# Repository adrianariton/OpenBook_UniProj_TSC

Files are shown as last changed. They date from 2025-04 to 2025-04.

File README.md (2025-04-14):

# Ariton Adrian TSC - proiect

# Implementation Steps

1. **Schematic Creation**
2. **Push to 2D PCB**
3. **Routing**
   - GND plane  
   - Net Class for Power Trails  
   - Custom rules & constraints upload  
   - Routing
4. **3D Models Design from Datasheets**
   - Battery  
   - Screen

---

# Hardware Modules and Components

## ESP32-C6-WROOM-1-N8 – Main Microcontroller
- WiFi 6, Bluetooth 5 LE, RISC-V core  
- Power Supply: 3.3V  
- Communications: SPI, I2C, UART, GPIO  

## SD Card Module
- Interface: SPI  
- Pins Used:
  - `SS_SD` → IO4  
  - `MOSI` → IO7  
  - `MISO` → IO2  
  - `SCK` → IO6  

## E-Paper Display
- Interface: SPI  
- Pins Used:
  - `EPD_CS` → IO10  
  - `EPD_DC` → IO5  
  - `EPD_RST` → IO23  
  - `EPD_BUSY` → IO3 (shared with MISO)  
  - MOSI, SCK (shared with SD)

## RTC Module - DS3231SN
- Interface: I2C  
- Pins Used:
  - `SCL` → IO22  
  - `SDA` → IO21  
  - `INT_RTC` → IO8  
  - `32KHZ` → IO1  
  - `RTC_RST` → IO18  

## Environmental Sensor - BME688
- Interface: I2C (shared with RTC)  
- Power Supply: 3.3V  

## External Flash - NORFlash64MB
- Interface: SPI  
- Pins Used:
  - `FLASH_CS` → IO12  
  - Rest (MOSI, MISO, SCK) shared  

## SD/USB Interface
- `USB_D+` → IO13  
- `USB_D-` → IO12  

## Reset and Boot Buttons
- `IO/BOOT` → IO9  
- `RESET` → EN  

## Li-Po Battery Charging Controller
- TP4056 or similar  
- Built-in charging control  
- Battery level monitoring with:
  - Battery ChargeLevel IC → I2C (IO19, IO20)

## Qwiic / Stemma QT Connector
- Communicates entirely via I2C  

## SPI ESD Protection Lines
- Protects the SPI lines for the SD card, e-paper, external flash  

## LDO Voltage Regulator
- Steps down 5V to 3.3V for ESP32-C6 and modules  

## Diodes
- For reverse polarity protection  

## USB-C Connector + ESD Protection
- Main power and data input  
- TVS diodes for ESD protection  

---

# 📊 Block Diagram: Schematic Design

```
+----------------+                                  +--------------------+
| USB C connector|                                  |      Buttons       |
|                |                                  |(Reset, Change, Boot|
+-------+--------+                                  |        IOs)        |
        |                                           +----------+---------+
        |                                                      |
+-------+--------+                                             |
|Battery Charging|                                             |
|  Controller    |-----------+                                   | USB
|   MCP73831     |           |                      +----------+---------+
+-------+--------+           |                      |                    |
        |                    |                      |                    |
        |          +----------------+    3v3 power  |                    |      +----------+
        |          |Voltage Regulator+------------->|                    |      |  SD Card  |
        |          |XC6220A331MR-G  |               |                    +----->|           |
        |          +--------+-------+               |                    |  SPI |    3v3    |
        |                   |                       |      ESP 32        |      +----------+
        |                   |                       |                    |
+-------+--------+          |                       |                    |      +----------+
|                |          |                       |        3v3         |      |NOR Flash  |
|     Battery    +----------+                       |                    +----->|           |
|                |                                  |                    |      |    3v3    |
+-------+--------+                                  |                    |      +----------+
        |                                           |                    |
        |                                           |                    |      +----------+
        |                    I2C                    |                    |      | Display   |
        |         +-------------+------------+------+                    +----->|           |
        |         |             |            |      +----------+---------+      |    3v3    |
        |   +----------+        |        +----------+          |                +----------+
        |   |          |        |        |          |          |         
        +---+ Battery  |  +-----+-----+  | BME688   |  +--------------+   
            | Level    |  |Real Time  |  | Sensor   |  | Stemma QT    |   
            |          |  |  Clock    |  |          |  |              |   
            |          |  |           |  |          |  |     3v3      |   
            +----------+  +-----------+  +----------+  +--------------+   

```



BOM:
Piece Name |	Piece Type (Optional) |	Link
--|--|--|
ESP32-CAP C0402 	|C |	https://componentsearchengine.com/part-view/CC0402MRX5R5BB106/YAGEO
ADAFRUIT_CHIP-LED0603 |	LED |	https://www.snapeda.com/parts/KP-1608SURCK/Kingbright/view-part/?ref=search&t=LED%200603
112ATAARR03 |	microSD |	https://www.snapeda.com/parts/112A-TAAR-R03/Attend/view-part/
744043680 |	L |	https://eu.mouser.com/ProductDetail/Wurth-Elektronik/744043680?qs=PGXP4M47uW6VkZq%252BkzjrHA%3D%3D
BD5229G-TR |	Voltage Detector |	https://www.snapeda.com/parts/BD5229G-TR/Rohm/view-part/?ref=search&t=BD5229G-TR
BUTTON_CUSYOMV1 |	Button |	https://www.snapeda.com/search/?q=EVQP7L01P&search-type=parts
CPH3225A |	C |	https://www.snapeda.com/parts/CPH3225A/Seiko/view-part/
DS3231SN# |	I²C-Integrated RTC/TCXO/Crystal |	https://www.snapeda.com/parts/DS3231SN%23/Analog%20Devices/view-part/?ref=search&t=DS3231SN%23
ESP32-C6-WROOM-1-N8 |	ESP32 |	https://www.snapeda.com/parts/ESP32-C6-WROOM-1-N8/Espressif%20Systems/view-part/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
ESP VARSISTOR |	Varsistor (B72520T0350K062) |	https://ro.mouser.com/ProductDetail/EPCOS-TDK/B72520T0350K062?qs=dEfas%2FXlABIszF52uu7vrg%3D%3D
ESP32_WROVER_AVX---SD0805S020S1R0 |	DIODE SCHOTTKY |	https://componentsearchengine.com/part-view/SD0805S020S1R0/Kyocera%20AVX
ESP32_WROVER_BME680_BME680 |	Env Senzor |	https://www.snapeda.com/parts/BME680/Bosch%20Sensortec/view-part/?ref=search&t=bme680
ESP32_WROVER_EAGLE-LTSPICE_R |	R |	https://componentsearchengine.com/part-view/R0402%201%25%20100%20K%20(RC0402FR-07100KL)/YAGEO
ESP32_WROVER_SPARKFUN-DISCRETESEMI_MOSFET_PCH |	T DMG2305UX-7 |	https://componentsearchengine.com/part-view/DMG2305UX-7/Diodes%20Incorporated
ESP32_WROVER_SPARKFUN-IC-POWER_MCP73831 |	TINY INTEGRATED LI-ION/LI-POLY CHARGE MGNT CONTROLLER |	https://componentsearchengine.com/part-view/MCP73831T-2ACI%2FOT/Microchip
FH34SRJ-24S-0.5SH_99_ |	FH34SRJ-24S-0.5SH(99) |	https://componentsearchengine.com/part-view/FH34SRJ-24S-0.5SH(99)/Hirose
MAX17048G+T10 |	Cell Fuel Gauge with ModelGauge |	https://www.snapeda.com/parts/MAX17048G+T10/Analog%20Devices/view-part/
MBR0530 |	Diode Schottky |	https://www.snapeda.com/parts/MBR0530/Onsemi/view-part/
PGB1010603MR |	Ipp Tvs Diode Surface Mount 0603 |	https://www.snapeda.com/parts/PGB1010603MR/Littelfuse/view-part/
QWIIC_CONNECTOR |	PRT-14417 QWIIC_CONNECTOR |	https://www.snapeda.com/parts/PRT-14417/SparkFun/view-part/
RCL_CPOL-EU |	C pol |	https://grabcad.com/library/tantalum-smd-capacitor-type-b-3528-1
SAMACSYS_PARTS_USB4110-GF-A |	USB4110-GF-A |	https://www.snapeda.com/parts/USB4110-GF-A./Global%20Connector%20Technology/view-part/
SJ |	Jumper-SolderPasteJumper3way |	https://grabcad.com/library/solder-jumpers-1
TP |	Test-Pad |	self-made
SI1308EDL-T1-GE3 |	MOSFET Transistor |	https://www.snapeda.com/parts/SI1308EDL-T1-GE3/Vishay/view-part/
USBLC6-2SC6Y |	Ipp Tvs Diode Surface Mount |	https://www.snapeda.com/parts/USBLC6-2SC6Y/STMicroelectronics/view-part/?ref=dk&t=USBLC6-2SC6Y&con_ref=None
W25Q512JVEIQ |	FLASH - NOR Memory |	https://www.snapeda.com/parts/W25Q512JVEIQ/Winbond%20Electronics/view-part/?ref=search&t=W25Q512JVEIQ
XC6220A331MR-G |	Voltage Regulator |	https://ro.mouser.com/ProductDetail/Torex-Semiconductor/XC6220A331MR-G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

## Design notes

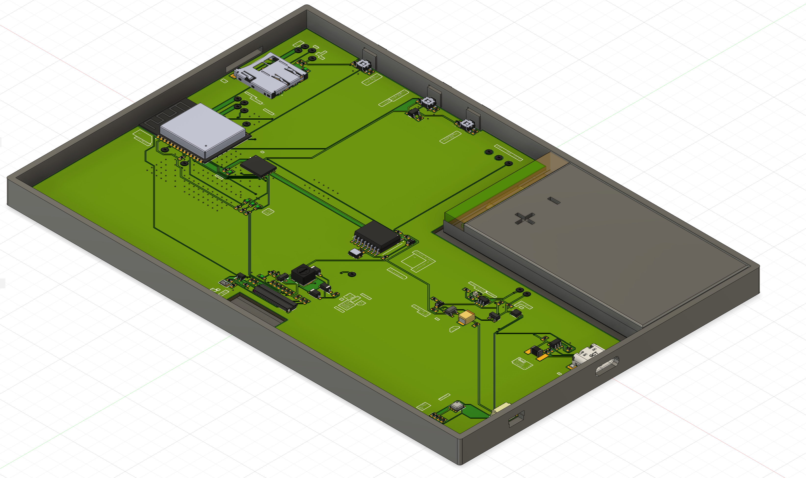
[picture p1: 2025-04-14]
Images/full_home_no_lid.png

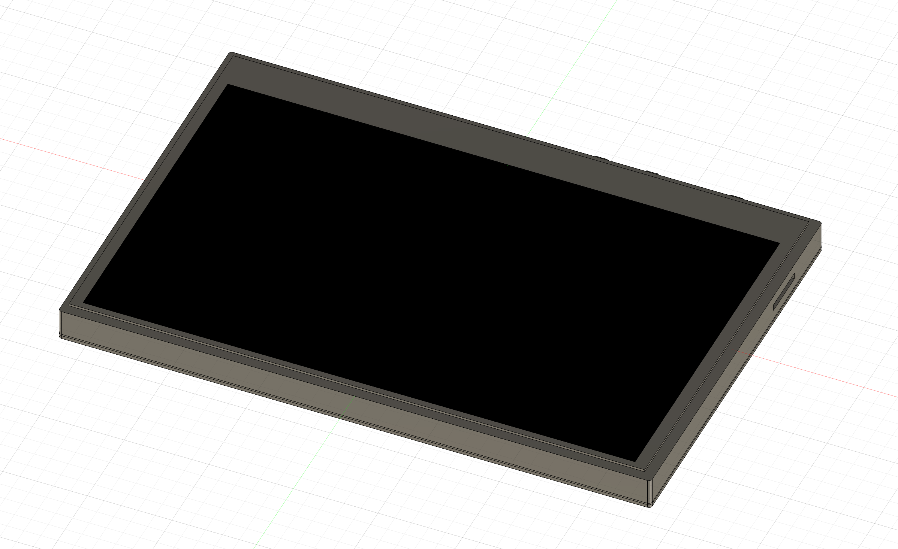
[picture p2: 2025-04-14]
Images/full_home_lid.png

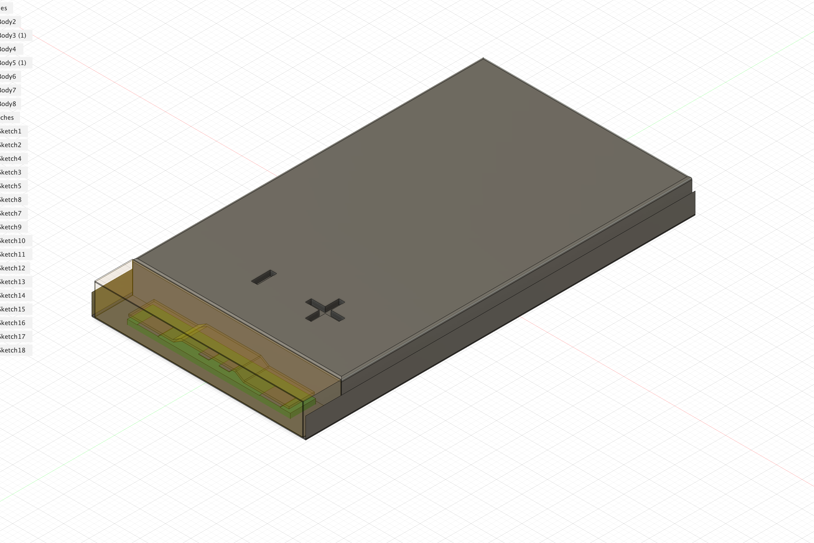
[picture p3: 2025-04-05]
Images/battery_home.png

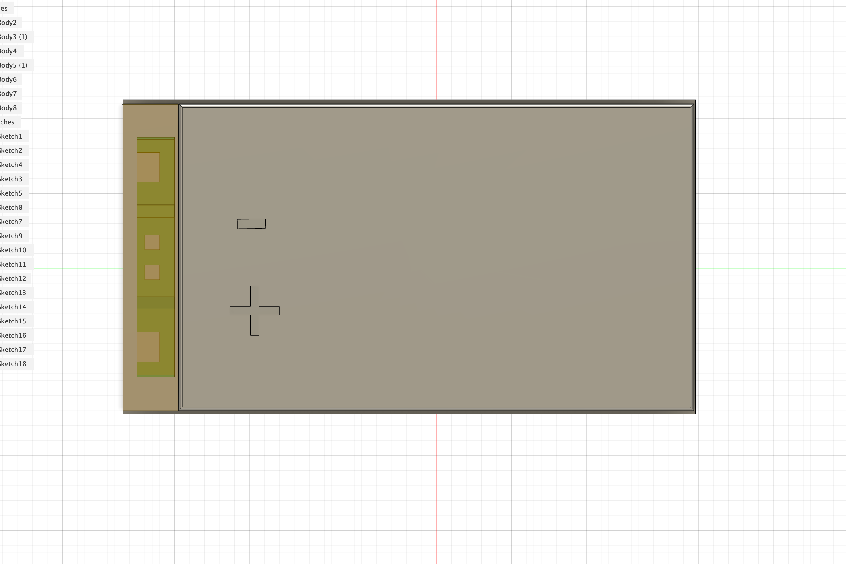
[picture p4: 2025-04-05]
Images/battery_top.png

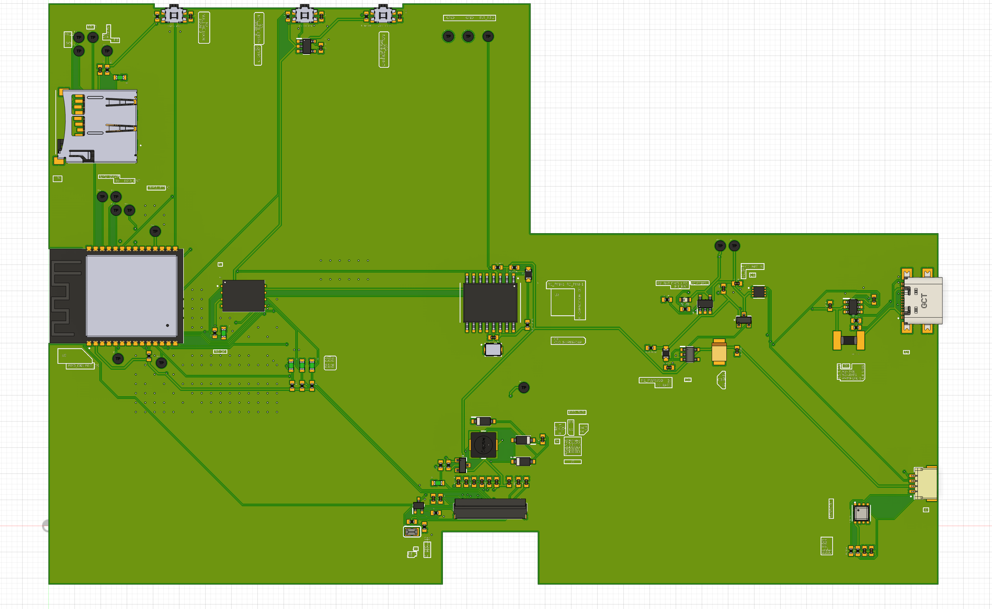
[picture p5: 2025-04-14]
Images/pcb_top.png

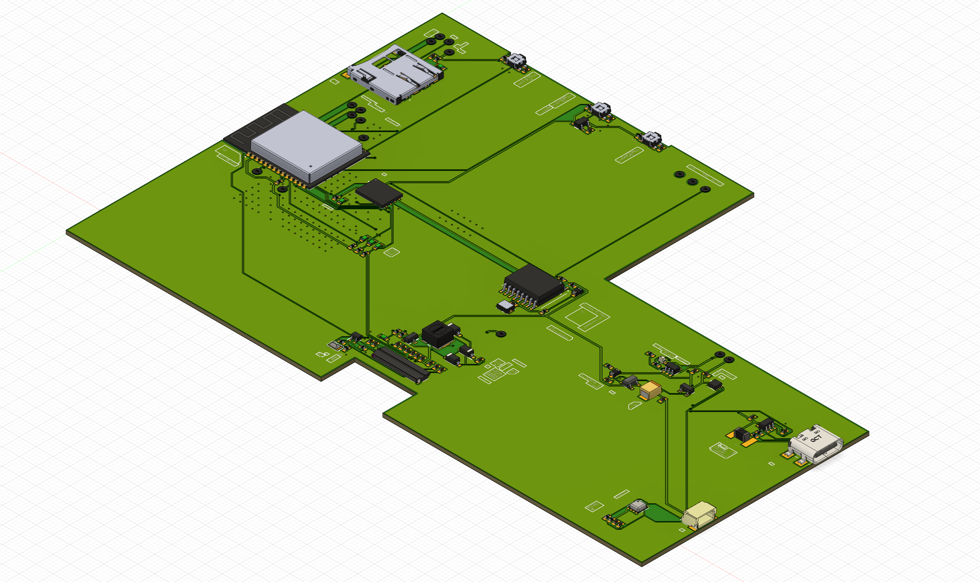
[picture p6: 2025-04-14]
Images/pcb_home.png

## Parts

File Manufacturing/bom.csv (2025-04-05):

Qty | Value | Device | Package | Parts | Description | ARROW_PART_NUMBER | ARROW_PRICE-STOCK | AVAILABILITY | CENTROID_NOT_SPECIFIED | CHECK_PRICES | COPYRIGHT | DATASHEET | DESCRIPTION | DIGIKEY_DESCRIPTION | DIGIKEY_PART_NUMBER | HEIGHT | LEAD_FREE | MANUFACTURER_NAME | MANUFACTURER_PART_NUMBER | MF | MFR_NAME | MOUSER_PART_NUMBER | MOUSER_PRICE-STOCK | MOUSER_TESTING_PART_NUMBER | MOUSER_TESTING_PRICE-STOCK | MP | MPN | PACKAGE | POPULARITY | PREFIX | PRICE | PROD_ID | PURCHASE-URL | ROHS | SNAPEDA_LINK | SPICEMODEL | SPICEPREFIX | TEMPERATURE_RANGE_HIGH | TEMPERATURE_RANGE_LOW | TP_SIGNAL_NAME | VALUE
1 |  | ADAFRUIT_LEDCHIP-LED0603 | ADAFRUIT_CHIP-LED0603 | CHG_LED | LED
1 |  | SJ | SJ | SJ1 | SMD solder JUMPER |  |  |  |  |  |  |  |  |  |  |  |  |  |  |  |  |  |  |  |  |  |  |  | 3
1 | 0.47 | ESP32_WROVER_EAGLE-LTSPICE_RR0402 | ESP32_WROVER_EAGLE-LTSPICE_R0402 | R3 | RESISTOR, European symbol |  |  |  |  |  |  |  |  |  |  |  |  |  |  |  |  |  |  |  |  |  |  |  |  |  |  |  |  |  |  | NONE | R
1 | 100K | ESP32_WROVER_EAGLE-LTSPICE_RR0402 | ESP32_WROVER_EAGLE-LTSPICE_R0402 | R1_PWRUSB | RESISTOR, European symbol |  |  |  |  |  |  |  |  |  |  |  |  |  |  |  |  |  |  |  |  |  |  |  |  |  |  |  |  |  |  | NONE | R
7 | 100nF | EAGLE-LTSPICE_CC0402 | EAGLE-LTSPICE_C0402 | C1, C2, C6, C8, C9, C10, C_DELAY | CAPACITOR, European symbol |  |  |  |  |  |  |  |  |  |  |  |  |  |  |  |  |  |  |  |  |  |  |  |  |  |  |  |  |  |  | NONE | C
1 | 100nF | ESP32_WROVER_EAGLE-LTSPICE_CC0402 | ESP32_WROVER_EAGLE-LTSPICE_C0402 | C4_USB | CAPACITOR, European symbol |  |  |  |  |  |  |  |  |  |  |  |  |  |  |  |  |  |  |  |  |  |  |  |  |  |  |  |  |  |  | NONE | C
1 | 100uF TNAT | RCL_CPOL-EUCT3528 | RCL_CT3528 | C3 | POLARIZED CAPACITOR, European symbol |  |  |  |  |  |  |  |  |  |  |  |  |  |  |  |  |  |  |  |  |  |  |  | 0 |  |  |  |  |  |  |  | C
16 | 10K | ESP32_WROVER_EAGLE-LTSPICE_RR0402 | ESP32_WROVER_EAGLE-LTSPICE_R0402 | R1, R1-PINH, R1-PINH1, R2-PINH, R2-PINH1, R4, R5, R6, R7, R8, R9, R10, R_BOOT, R_CHANGE, R_CL1, R_RESET | RESISTOR, European symbol |  |  |  |  |  |  |  |  |  |  |  |  |  |  |  |  |  |  |  |  |  |  |  |  |  |  |  |  |  |  | NONE | R
1 | 10uF | EAGLE-LTSPICE_CC0402 | EAGLE-LTSPICE_C0402 | C7 | CAPACITOR, European symbol |  |  |  |  |  |  |  |  |  |  |  |  |  |  |  |  |  |  |  |  |  |  |  |  |  |  |  |  |  |  | NONE | C
1 | 112A-TAAR-R03_ATTEND | 112A-TAAR-R03_ATTEND | 112ATAARR03ATTEND | J4 | Micro SD Card Socket, Push-Push Type, Top Mount, SMT, H=1.83mm, 10u |  |  |  |  |  |  |  | Micro SD Card Socket | Push-Push Type | Top Mount | SMT | H=1.83mm | 10u |  |  | 1.9mm |  | ATTEND | 112A-TAAR-R03 ATTEND
1 | 15 | ESP32_WROVER_EAGLE-LTSPICE_RR0402 | ESP32_WROVER_EAGLE-LTSPICE_R0402 | R_CAPACITOR | RESISTOR, European symbol |  |  |  |  |  |  |  |  |  |  |  |  |  |  |  |  |  |  |  |  |  |  |  |  |  |  |  |  |  |  | NONE | R
1 | 1uF | EAGLE-LTSPICE_CC0402 | EAGLE-LTSPICE_C0402 | C5 | CAPACITOR, European symbol |  |  |  |  |  |  |  |  |  |  |  |  |  |  |  |  |  |  |  |  |  |  |  |  |  |  |  |  |  |  | NONE | C
10 | 1uF/50V | EAGLE-LTSPICE_CC0402 | EAGLE-LTSPICE_C0402 | EPD_C1, EPD_C2, EPD_C5, EPD_C6, EPD_C7, EPD_C8, EPD_C9, EPD_C10, EPD_C11, EPD_C12 | CAPACITOR, European symbol |  |  |  |  |  |  |  |  |  |  |  |  |  |  |  |  |  |  |  |  |  |  |  |  |  |  |  |  |  |  | NONE | C
1 | 2.2 | ESP32_WROVER_EAGLE-LTSPICE_RR0402 | ESP32_WROVER_EAGLE-LTSPICE_R0402 | R2 | RESISTOR, European symbol |  |  |  |  |  |  |  |  |  |  |  |  |  |  |  |  |  |  |  |  |  |  |  |  |  |  |  |  |  |  | NONE | R
1 | 200 | ESP32_WROVER_EAGLE-LTSPICE_RR0402 | ESP32_WROVER_EAGLE-LTSPICE_R0402 | R1_BAT | RESISTOR, European symbol |  |  |  |  |  |  |  |  |  |  |  |  |  |  |  |  |  |  |  |  |  |  |  |  |  |  |  |  |  |  | NONE | R
2 | 20V/4.2A/52mΩ/1.4W | ESP32_WROVER_SPARKFUN-DISCRETESEMI_MOSFET_PCH-DMG2305UX-7 | ESP32_WROVER_SPARKFUN-DISCRETESEMI_SOT23-3 | Q1, Q2 | P-channel MOSFETs |  |  |  |  |  |  |  |  |  |  |  |  |  |  |  |  |  |  |  |  |  |  |  |  |  |  | TRAN-14388 |  |  |  |  |  |  |  |  | 20V/4.2A/52mΩ/1.4W
1 | 2K | ESP32_WROVER_EAGLE-LTSPICE_RR0402 | ESP32_WROVER_EAGLE-LTSPICE_R0402 | R2_BAT | RESISTOR, European symbol |  |  |  |  |  |  |  |  |  |  |  |  |  |  |  |  |  |  |  |  |  |  |  |  |  |  |  |  |  |  | NONE | R
2 | 4.7uF | EAGLE-LTSPICE_CC0402 | EAGLE-LTSPICE_C0402 | C1_BAT, C2_BAT | CAPACITOR, European symbol |  |  |  |  |  |  |  |  |  |  |  |  |  |  |  |  |  |  |  |  |  |  |  |  |  |  |  |  |  |  | NONE | C
3 | 4.7uF | ESP32_WROVER_EAGLE-LTSPICE_CC0402 | ESP32_WROVER_EAGLE-LTSPICE_C0402 | C1_BAT1, C1_BAT2, C5_USB | CAPACITOR, European symbol |  |  |  |  |  |  |  |  |  |  |  |  |  |  |  |  |  |  |  |  |  |  |  |  |  |  |  |  |  |  | NONE | C
1 | 4.7uF/25V | EAGLE-LTSPICE_CC0402 | EAGLE-LTSPICE_C0402 | C4 | CAPACITOR, European symbol |  |  |  |  |  |  |  |  |  |  |  |  |  |  |  |  |  |  |  |  |  |  |  |  |  |  |  |  |  |  | NONE | C
2 | 5k1 | ESP32_WROVER_EAGLE-LTSPICE_RR0402 | ESP32_WROVER_EAGLE-LTSPICE_R0402 | R2-USB, R2-USB1 | RESISTOR, European symbol |  |  |  |  |  |  |  |  |  |  |  |  |  |  |  |  |  |  |  |  |  |  |  |  |  |  |  |  |  |  | NONE | R
1 | 68uH | 744043680IND_4828-WE-TPC_WRE | IND_4828-WE-TPC_WRE | L1 |  |  |  |  |  |  | Copyright (C) 2024 Ultra Librarian. All rights reserved. |  |  |  |  |  |  |  | 744043680 |  | Wurth Electronics
1 | BD5229G-TR | BD5229G-TR | SOT95P280X125-5N | IC1 | Voltage Detector with Adjustable Delay Time: CMOS processes are utilized to develop high precision, low current consumption CMOS reset ICs that allow arbitrary setting of the delay time. The extensive lineup includes both Nch Open Drain and CMOS output types in a wide range of detection voltages (from 2.3V to 6.0V, in 0.1V steps), enabling selection of the ideal solution based on customer requirements. In addition, the entire series is of course both lead-free and RoHS-compliant. |  |  |  |  |  |  |  | Voltage Detector with Adjustable Delay Time: CMOS processes are utilized to develop high precision | low current consumption CMOS reset ICs that allow arbitrary setting of the delay time. The extensive lineup includes both Nch Open Drain and CMOS output types in a wide range of detection voltages (from 2.3V to 6.0V | in 0.1V steps) | enabling selection of the ideal solution based on customer requirements. In addition | the entire series is of course both lead-free and RoHS-compliant. |  |  | 1.25mm |  | ROHM Semiconductor | BD5229G-TR |  |  | 755-BD5229G-TR | https://www.mouser.co.uk/ProductDetail/ROHM-Semiconductor/BD5229G-TR?qs=4kLU8WoGk0vvnhrrYwdszw%3D%3D
3 | BUTTON_CUSYOMV1 | BUTTON_CUSYOMV1 | MYBUTTON | BOOT_BUTTON, CHANGE_BUTTON, RESET_BUTTON
1 | CPH3225A | CPH3225A | CAPCP3225X100N | C10_SUPERCAP | Cap 0.011F 3.3V 1210 Flat Check availability |  |  | Not in stock |  | https://www.snapeda.com/parts/CPH3225A/Seiko+Instruments/view-part/?ref=eda |  |  | 11 mF (EDLC) Supercapacitor 3.3 V 1210 (3225 Metric) - - |  |  |  |  |  |  | Seiko Instruments |  |  |  |  |  | CPH3225A |  | 1210 Seiko |  |  | None |  | https://www.snapeda.com/api/url_track_click_mouser/?unipart_id=562593&manufacturer=Seiko Instruments&part_name=CPH3225A&search_term=None |  | https://www.snapeda.com/parts/CPH3225A/Seiko+Instruments/view-part/?ref=snap
1 | DS3231SN# | DS3231SN# | SOIC127P1032X265-16N | U3 | Real Time Clock Serial 16-Pin SOIC W T/R Check availability |  |  | In Stock |  | https://www.snapeda.com/parts/DS3231SN%23/Analog+Devices/view-part/?ref=eda |  |  | Extremely Accurate I²C-Integrated RTC/TCXO/Crystal |  |  |  |  |  |  | Analog Devices |  |  |  |  |  | DS3231SN# |  | SOIC-16 Maxim |  |  | None |  | https://www.snapeda.com/api/url_track_click_mouser/?unipart_id=99048&manufacturer=Analog Devices&part_name=DS3231SN#&search_term=None |  | https://www.snapeda.com/parts/DS3231SN%23/Analog+Devices/view-part/?ref=snap
1 | ESP32-C6-WROOM-1-N8 | ESP32-C6-WROOM-1-N8 | XCVR_ESP32-C6-WROOM-1-N8 | U2 | Check availability |  |  | In Stock |  | https://www.snapeda.com/parts/ESP32-C6-WROOM-1-N8/Espressif+Systems/view-part/?ref=eda |  |  | Multiprotocol Modules ESP32-C6 module | Wi-Fi 6 in 2.4 GHz band | Bluetooth 5 | Zigbee 3.0 and Thread. ESP34-WROOM Compatible - ENGINEERING SAMPLE |  |  |  |  |  |  | Espressif Systems |  |  |  |  |  | ESP32-C6-WROOM-1-N8 |  | None |  |  | None |  |  |  | https://www.snapeda.com/parts/ESP32-C6-WROOM-1-N8/Espressif+Systems/view-part/?ref=snap
1 | ESP32C6_VARISTORCN1812 | ESP32C6_VARISTORCN1812 | ESP32C6_VARISTOR_CT/CN1812 | PFMF.050.1 | VARISTOR |  |  |  |  |  |  |  |  |  |  |  |  |  |  |  |  |  |  |  |  |  |  |  | 0
2 | ESP32_WROVER_AVX---SD0805S020S1R0_AVX_SD0805S020S1R0_0_0AVX_SD0805S020S1R0_0_0 | ESP32_WROVER_AVX---SD0805S020S1R0_AVX_SD0805S020S1R0_0_0AVX_SD0805S020S1R0_0_0 | ESP32_WROVER_AVX---SD0805S020S1R0_AVX_SD0805S020S1R0_0 | D2, D7 | Schottky Barrier Rectifier Diode |  |  |  | No |  |  | http://datasheets.avx.com/schottky.pdf |  | DIODE SCHOTTKY 20V 1A 0805 | 478-7800-1-ND |  | yes |  |  | AVX |  | 581-SD0805S020S1R0 |  |  |  |  |  | 0805 (2012 metric) |  | D |  |  |  | yes |  |  |  | +125°C | -55°C
1 | ESP32_WROVER_BME680_BME680 | ESP32_WROVER_BME680_BME680 | ESP32_WROVER_BME680_PSON80P300X300X100-8N | SENSOR2 | Integrated Environmental Unit |  |  | Unavailable |  |  |  |  | Integrated Environmental Unit |  |  |  |  |  |  | Bosch Sensortec |  |  |  |  |  | BME680 |  | LGA-8 Bosch Tools |  |  | None
1 | ESP32_WROVER_SPARKFUN-IC-POWER_MCP73831 | ESP32_WROVER_SPARKFUN-IC-POWER_MCP73831 | SOT95P280X125-5N | MCP73831 | MCP73831T Li-Ion, Li-Pol Controller |  |  |  |  |  |  |  |  |  |  |  |  |  |  |  |  |  |  |  |  |  |  |  |  |  |  | IC-09995
1 | FH34SRJ-24S-0.5SH_99_ | FH34SRJ-24S-0.5SH_99_ | FH34SRJ24S05SH99 | J1 | (0.50mm) Surface Mount, Right Angle |  |  |  |  |  |  |  | 24 Position FFC | FPC Connector Contacts | (0.50mm) Surface Mount | Right Angle |  |  | 1.1mm |  | Hirose | FH34SRJ-24S-0.5SH(99) |  |  | 798-FH34SRJ24S05SH99 | https://www.mouser.co.uk/ProductDetail/Hirose-Connector/FH34SRJ-24S-0.5SH99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
1 | MAX17048G+T10 | MAX17048G+T10 | SON50P200X200X80-9N | U4 | Check availability |  |  | In Stock |  | https://www.snapeda.com/parts/MAX17048G+T10/Analog+Devices/view-part/?ref=eda |  |  | 3µA 1-Cell/2-Cell Fuel Gauge with ModelGauge |  |  |  |  |  |  | Analog Devices |  |  |  |  |  | MAX17048G+T10 |  | TDFN-8 Maxim |  |  | None |  | https://www.snapeda.com/api/url_track_click_mouser/?unipart_id=329239&manufacturer=Analog Devices&part_name=MAX17048G+T10&search_term=None |  | https://www.snapeda.com/parts/MAX17048G+T10/Analog+Devices/view-part/?ref=snap
3 | MBR0530 | MBR0530 | SOD3716X135N | D3, D4, D5 | ON SEMICONDUCTOR - MBR0530 - DIODE, SCHOTTKY, 0.5A, 30V, SOD-123 |  |  | In Stock |  | https://www.snapeda.com/parts/MBR0530/Onsemi/view-part/?ref=eda |  |  | Diode Schottky 30 V 500mA Surface Mount SOD-123 |  |  |  |  |  |  | ON Semiconductor |  |  |  |  |  | MBR0530 |  | SOD-123-2 ON Semiconductor |  |  | None |  | https://www.snapeda.com/api/url_track_click_mouser/?unipart_id=179458&manufacturer=ON Semiconductor&part_name=MBR0530&search_term=None |  | https://www.snapeda.com/parts/MBR0530/Onsemi/view-part/?ref=snap
6 | PGB1010603MR | PGB1010603MR | DIOC1608X36N | D6, D8, D9, D10, D11, D12 | Check availability |  |  | In Stock |  | https://www.snapeda.com/parts/PGB1010603MR/Littelfuse/view-part/?ref=eda |  |  | 150V (Typ) Clamp - Ipp Tvs Diode Surface Mount 0603 (1608 Metric) |  |  |  |  |  |  | Littelfuse Inc. |  |  |  |  |  | PGB1010603MR |  | 0603 Littelfuse Inc. |  |  | None |  | https://www.snapeda.com/api/url_track_click_mouser/?unipart_id=5659453&manufacturer=Littelfuse Inc.&part_name=PGB1010603MR&search_term=None |  | https://www.snapeda.com/parts/PGB1010603MR/Littelfuse/view-part/?ref=snap
1 | QWIIC_RIGHT_ANGLE | QWIIC_CONNECTORJS-1MM | JST04_1MM_RA | J3 | SparkFun I2C Standard Qwiic Connector |  |  |  |  |  |  |  |  |  |  |  |  |  |  |  |  |  |  |  |  |  |  |  |  |  |  | CONN-13694 |  |  |  |  |  |  |  |  | QWIIC_RIGHT_ANGLE
1 | SAMACSYS_PARTS_USB4110-GF-A | SAMACSYS_PARTS_USB4110-GF-A | SAMACSYS_PARTS_USB4110GFA | J2 | CONN USB 2.0 TYPE-C R/A SMT |  |  |  |  |  |  |  | CONN USB 2.0 TYPE-C R/A SMT |  |  | 3.26mm |  | GCT (GLOBAL CONNECTOR TECHNOLOGY) | USB4110-GF-A |  |  | 640-USB4110-GF-A | https://www.mouser.co.uk/ProductDetail/GCT/USB4110-GF-A?qs=KUoIvG%2F9IlYiZvIXQjyJeA%3D%3D
1 | SI1308EDL-T1-GE3 | SI1308EDL-T1-GE3 | SOT65P210X110-3N | Q3 | MOSFET N-Ch 30V 1.5A TrenchFET SC70 Vishay Si1308EDL-T1-GE3 N-channel MOSFET Transistor, 1.5 A, 30 V, 3-Pin SC-70 |  |  | In Stock |  | https://www.snapeda.com/parts/SI1308EDL-T1-GE3/Vishay+Siliconix/view-part/?ref=eda |  |  | Si1308EDL-T1-GE3 N-channel MOSFET Transistor | 1.5 A | 30 V | 3-Pin SC-70 | Siliconix / Vishay SI1308EDL-T1-GE3 |  |  |  |  |  |  | Vishay Siliconix |  |  |  |  |  | SI1308EDL-T1-GE3 |  | SOT-323 Vishay Semiconductor |  |  | None |  | https://www.snapeda.com/api/url_track_click_mouser/?unipart_id=274603&manufacturer=Vishay Siliconix&part_name=SI1308EDL-T1-GE3&search_term=None |  | https://www.snapeda.com/parts/SI1308EDL-T1-GE3/Vishay+Siliconix/view-part/?ref=snap
17 | TPTP20R | TPTP20R | TP20R | TP1, TP2, TP3, TP4, TP5, TP6, TP7, TP8, TP9, TP10, TP11, TP12, TP13, TP14, TP15, TP16, TP17 | Test pad |  |  |  |  |  |  |  |  |  |  |  |  |  |  |  |  |  |  |  |  |  |  |  | 2
1 | USBLC6-2SC6Y | USBLC6-2SC6Y | SOT95P280X145-6N | D1 | Low Cap. ESD Protection Auto SOT-23-6 STMicroelectronics USBLC6-2SC6Y, Dual Uni-Directional TVS Diode Array, 6-Pin SOT-23 |  |  | In Stock |  | https://www.snapeda.com/parts/USBLC6-2SC6Y/STMicroelectronics/view-part/?ref=eda |  |  | 17V Clamp 5A (8/20µs) Ipp Tvs Diode Surface Mount SOT-23-6 |  |  |  |  |  |  | STMicroelectronics |  |  |  |  |  | USBLC6-2SC6Y |  | SOT-23-6 STMicroelectronics |  |  | None |  |  |  | https://www.snapeda.com/parts/USBLC6-2SC6Y/STMicroelectronics/view-part/?ref=snap
1 | W25Q512JVEIQ | W25Q512JVEIQ | SON127P600X800X80-9N | U1 | Check availability |  |  | In Stock |  | https://www.snapeda.com/parts/W25Q512JVEIQ/Winbond+Electronics/view-part/?ref=eda |  |  | FLASH - NOR Memory IC 512Mb (64M x 8) SPI - Quad I/O 133 MHz 8-WSON (8x6) |  |  |  |  |  |  | Winbond Electronics |  |  |  |  |  | W25Q512JVEIQ |  | Package |  |  | None |  |  |  | https://www.snapeda.com/parts/W25Q512JVEIQ/Winbond+Electronics/view-part/?ref=snap
1 | XC6220A331MR-G | XC6220A331MR-G | SOT95P280X120-5N | IC4 | LDO Voltage Regulators |  |  |  |  |  |  |  | LDO Voltage Regulators |  |  | 1.2mm |  | Torex | XC6220A331MR-G |  |  | 865-XC6220A331MR-G | https://www.mouser.co.uk/ProductDetail/Torex-Semiconductor/XC6220A331MR-G?qs=AsjdqWjXhJ8ZSWznL1J0gg%3D%3D

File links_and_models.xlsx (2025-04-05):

NrCrt | Part | Value | Link
ESP32-CAP C0402 | C
ADAFRUIT_CHIP-LED0603 | LED |  | https://www.snapeda.com/parts/7012X1/VCC/view-part/?ref=search&t=led
112ATAARR03 |  |  | https://www.snapeda.com/parts/112A-TAAR-R03/Attend/view-part/
Bobina |  |  | https://eu.mouser.com/ProductDetail/Wurth-Elektronik/744043680?qs=PGXP4M47uW6VkZq%252BkzjrHA%3D%3D
BD5229G-TR |  |  | https://www.snapeda.com/parts/BD5229G-TR/Rohm/view-part/?ref=search&t=BD5229G-TR
BUTTON_CUSYOMV1 |  |  | https://industry.panasonic.com/global/en/downloads?tab=cad&small_g_cd=203&part_no=EVQPUJ02K |  |  |  |  | EVQPUJ02K | Small-sized Side-operational SMD |  |  | https://www.snapeda.com/search/?q=EVQP7L01P&search-type=parts
CPH3225A | C |  | https://www.snapeda.com/parts/CPH3225A/Seiko/view-part/
DS3231SN# |  |  | https://www.snapeda.com/parts/DS3231SN%23/Analog%20Devices/view-part/?ref=search&t=DS3231SN%23
ESP32-C6-WROOM-1-N8 |  |  | https://www.snapeda.com/parts/ESP32-C6-WROOM-1-N8/Espressif%20Systems/view-part/?t=ESP32-C6-WROOM-1-N8
ESP VARSISTOR |  |  | https://ro.mouser.com/ProductDetail/EPCOS-TDK/B72520T0350K062?qs=dEfas%2FXlABIszF52uu7vrg%3D%3D |  |  |  | B72520T0350K062.stp | https://www.snapeda.com/parts/MOV-10D561K/Bourns/view-part/?welcome=home&ref=search&t=varistor |  |  |  | MOV-10D561K
ESP32_WROVER_AVX---SD0805S020S1R0_AVX_SD0805S020S1R0_0_0 |  |  | https://componentsearchengine.com/part-view/SD0805S020S1R0/Kyocera%20AVX
ESP32_WROVER_BME680_BME680 | Envsenzor |  | https://www.snapeda.com/parts/BME680/Bosch%20Sensortec/view-part/?ref=search&t=bme680
ESP32_WROVER_EAGLE-LTSPICE_R | R |  | https://componentsearchengine.com/part-view/R0402%201%25%20100%20K%20(RC0402FR-07100KL)/YAGEO
ESP32_WROVER_SPARKFUN-DISCRETESEMI_MOSFET_PCH | T |  | https://componentsearchengine.com/part-view/DMG2305UX-7/Diodes%20Incorporated |  | DMG2305UX-7 Files
ESP32_WROVER_SPARKFUN-IC-POWER_MCP73831 |  |  | https://componentsearchengine.com/part-view/MCP73831T-2ACI%2FOT/Microchip |  |  |  |  | MCP73831T-2ACI/OT - Microchip
FH34SRJ-24S-0.5SH_99_
MAX17048G+T10 |  |  | https://www.snapeda.com/parts/MAX17048G+T10/Analog%20Devices/view-part/
MBR0530 |  |  | https://www.snapeda.com/parts/MBR0530/Onsemi/view-part/
PGB1010603MR |  |  | https://www.snapeda.com/parts/PGB1010603MR/Littelfuse/view-part/
QWIIC_CONNECTOR |  |  | https://www.snapeda.com/parts/PRT-14417/SparkFun/view-part/ |  | PRT-14417
RCL_CPOL-EU | C pol |  | https://grabcad.com/library/tantalum-smd-capacitor-type-b-3528-1
SAMACSYS_PARTS_USB4110-GF-A |  |  | https://www.snapeda.com/parts/USB4110-GF-A./Global%20Connector%20Technology/view-part/ |  |  |  |  | USB4110-GF-A.
SJ | Jumper |  | https://grabcad.com/library/solder-jumpers-1 | SolderPasteJumper3way |  | https://grabcad.com/library/solder-jumpers-1
TP | Test Pad
SI1308EDL-T1-GE3 |  |  | https://www.snapeda.com/parts/SI1308EDL-T1-GE3/Vishay/view-part/
USBLC6-2SC6Y |  |  | https://www.snapeda.com/parts/USBLC6-2SC6Y/STMicroelectronics/view-part/?t=USBLC6-2SC6Y&con_ref=None
W25Q512JVEIQ |  |  | https://www.snapeda.com/parts/W25Q512JVEIQ/Winbond%20Electronics/view-part/?t=W25Q512JVEIQ
XC6220A331MR-G |  |  | https://www.snapeda.com/parts/XC6220A331MR-G/Torex%20Semiconductor%20Ltd/view-part/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 |  |  |  |  |  | aici nu e:( | https://app.ultralibrarian.com/details/ec9e5b71-107d-11e9-ab3a-0a3560a4cccc/Torex-Semiconductor/XC6220B331MR-G |  |  | https://ro.mouser.com/ProductDetail/Torex-Semiconductor/XC6220A331MR-G?qs=AsjdqWjXhJ8ZSWznL1J0gg%3D%3D

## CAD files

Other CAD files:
Mechanical/Updated_OpenBookEnclosure2v16.f3z

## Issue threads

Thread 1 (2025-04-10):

Fix unfilled areas in GND plane

monica-raluca, 2025-04-10:
# Issue

There are unfilled areas in the GND plane

# Images

* Open 2D PCB and look for the black areas
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

# Fixes

* Go to the 2D PCB
- [x] Use vias to connect the GND plane with the empty space
* Take care to not overlap with any routes when fixing

adrianariton, 2025-04-14:
Will fix in the context of #2

adrianariton, 2025-04-14:
Fixed along with #2

Closed 2025-04-14.

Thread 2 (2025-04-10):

Add via stitching

monica-raluca, 2025-04-10:
# Issue

Stiching with viases between top and bottom GND planes is missing.

# Images

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

# Fixes
- [x] Open the pcb design and go to *Route* -> *Via Stiching*

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

- [x] Create polygons (using the *Fill Polygon Shape* option) where you want to connect the planes

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

- [x] Make sure it is connected especially around the ESP32 module

adrianariton, 2025-04-14:
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

Added 3 stitching planes as suggested to fix the empty holes on the 2D PCB and fixed the connections around the ESP module

Closed 2025-04-14.

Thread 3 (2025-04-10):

Add relevant silkscreen information

monica-raluca, 2025-04-10:
# Issue

Add relevant information to the silkscreen in the 3D design

# Fixes
- [x] Open the PCB design and add names next to the components
* Make sure to not include the values of the components

adrianariton, 2025-04-14:
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

Added the silk screen! :)

Closed 2025-04-14.

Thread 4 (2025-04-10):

Fix PCB Thickness

monica-raluca, 2025-04-10:
# Issues

The PCB thickness is not proper. It should be 1mm tall.

# Fix
* Open the PCB design
- [ ] Go to *Rules*->*Preferences*->*Layer Stack*->*Dielectric* and modify its size.

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

- [ ] Make sure to check the *Edit Material Properties* box to be able to edit the size.

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

- [ ] Modify the PCB thickness to 1mm.

# Other notes
The following guide might help:

https://forums.autodesk.com/t5/fusion-electronics/how-to-change-thickness-of-pcb-in-electronics-design/td-p/9367147

adrianariton, 2025-04-14:
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

Done w/ this as well:)

Closed 2025-04-14.

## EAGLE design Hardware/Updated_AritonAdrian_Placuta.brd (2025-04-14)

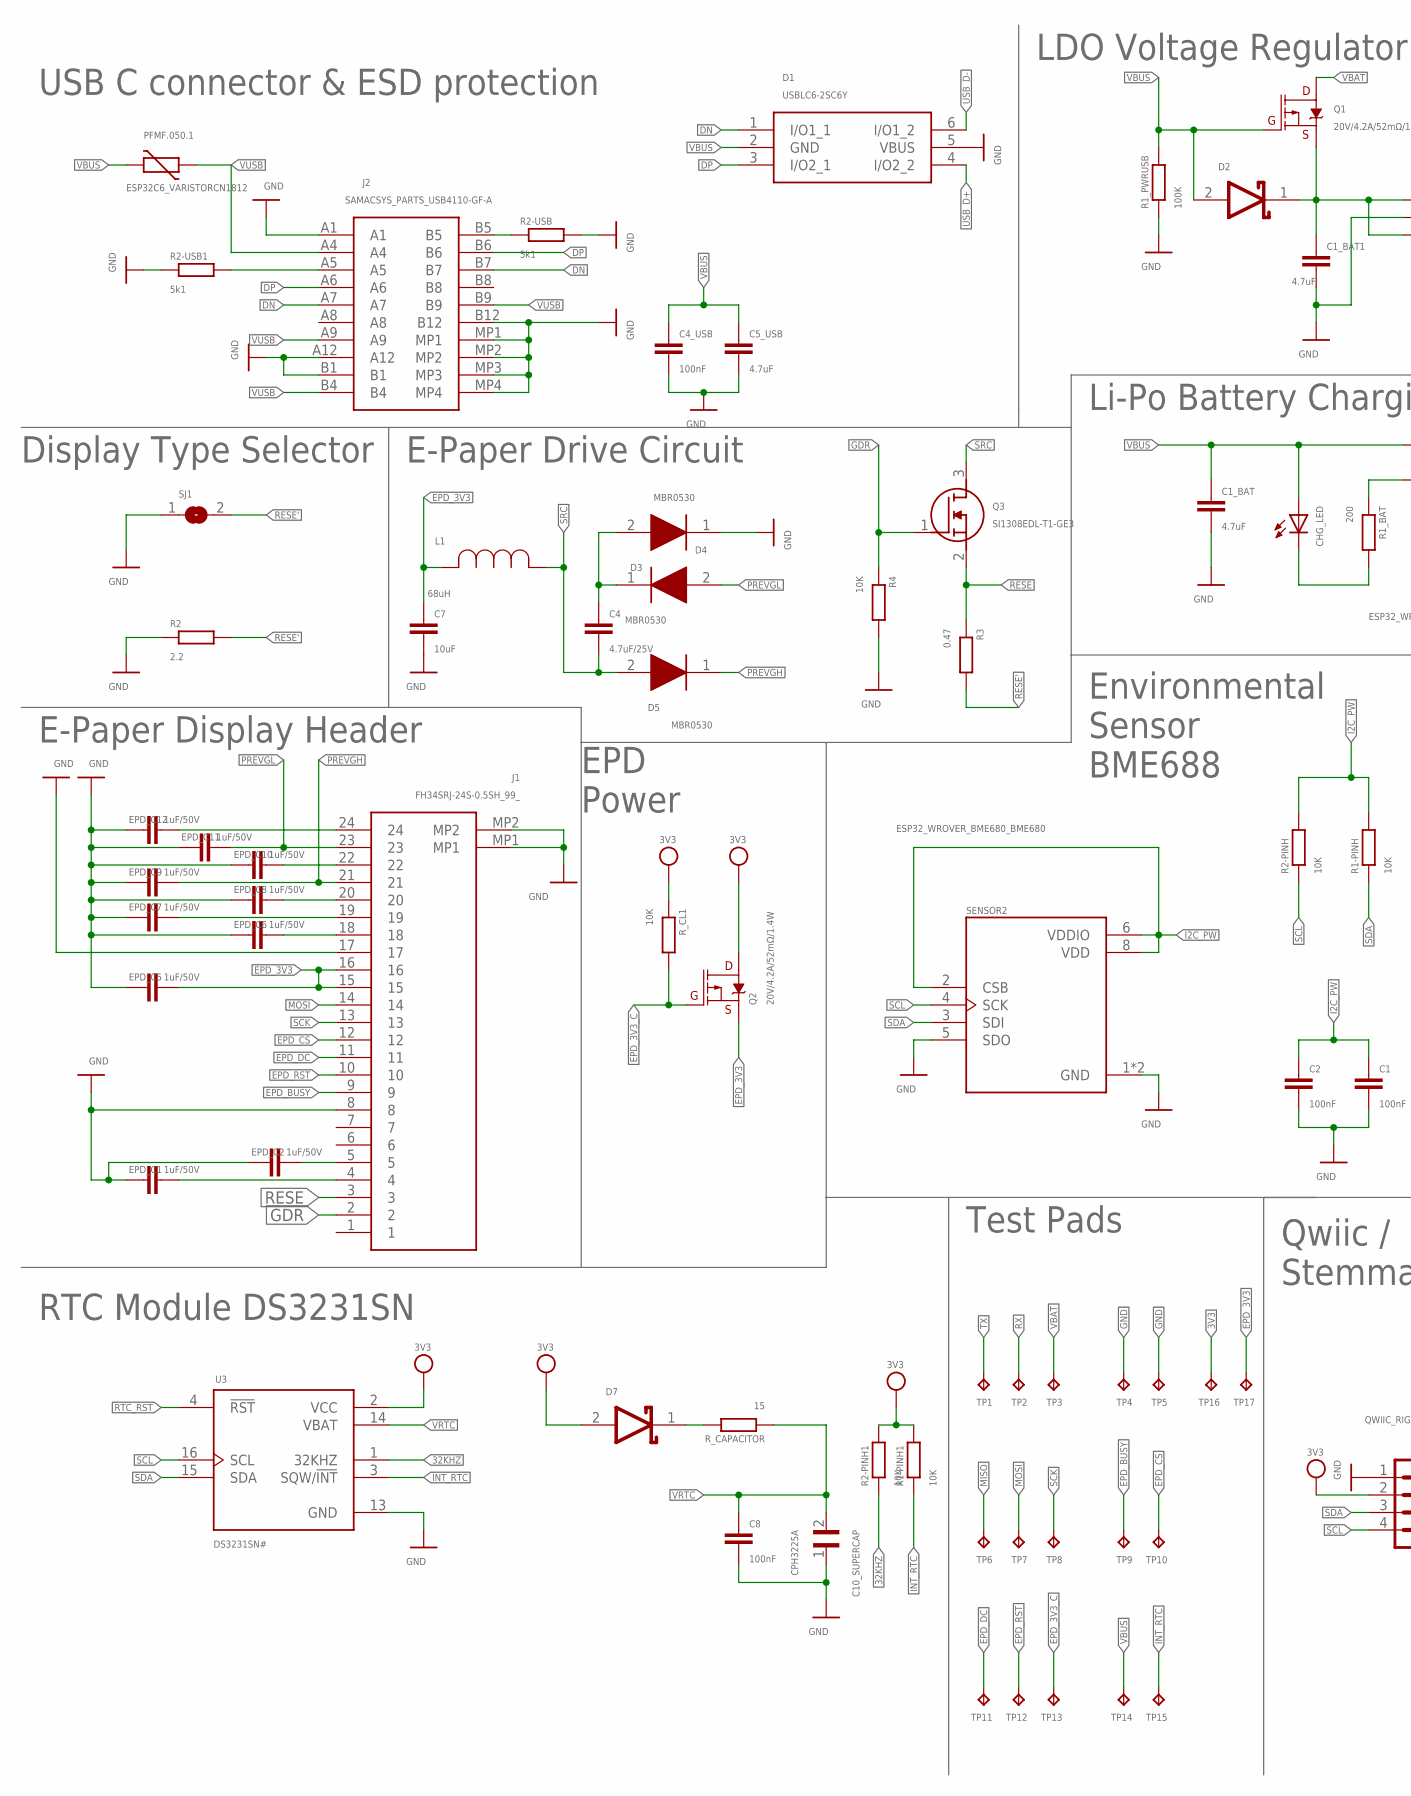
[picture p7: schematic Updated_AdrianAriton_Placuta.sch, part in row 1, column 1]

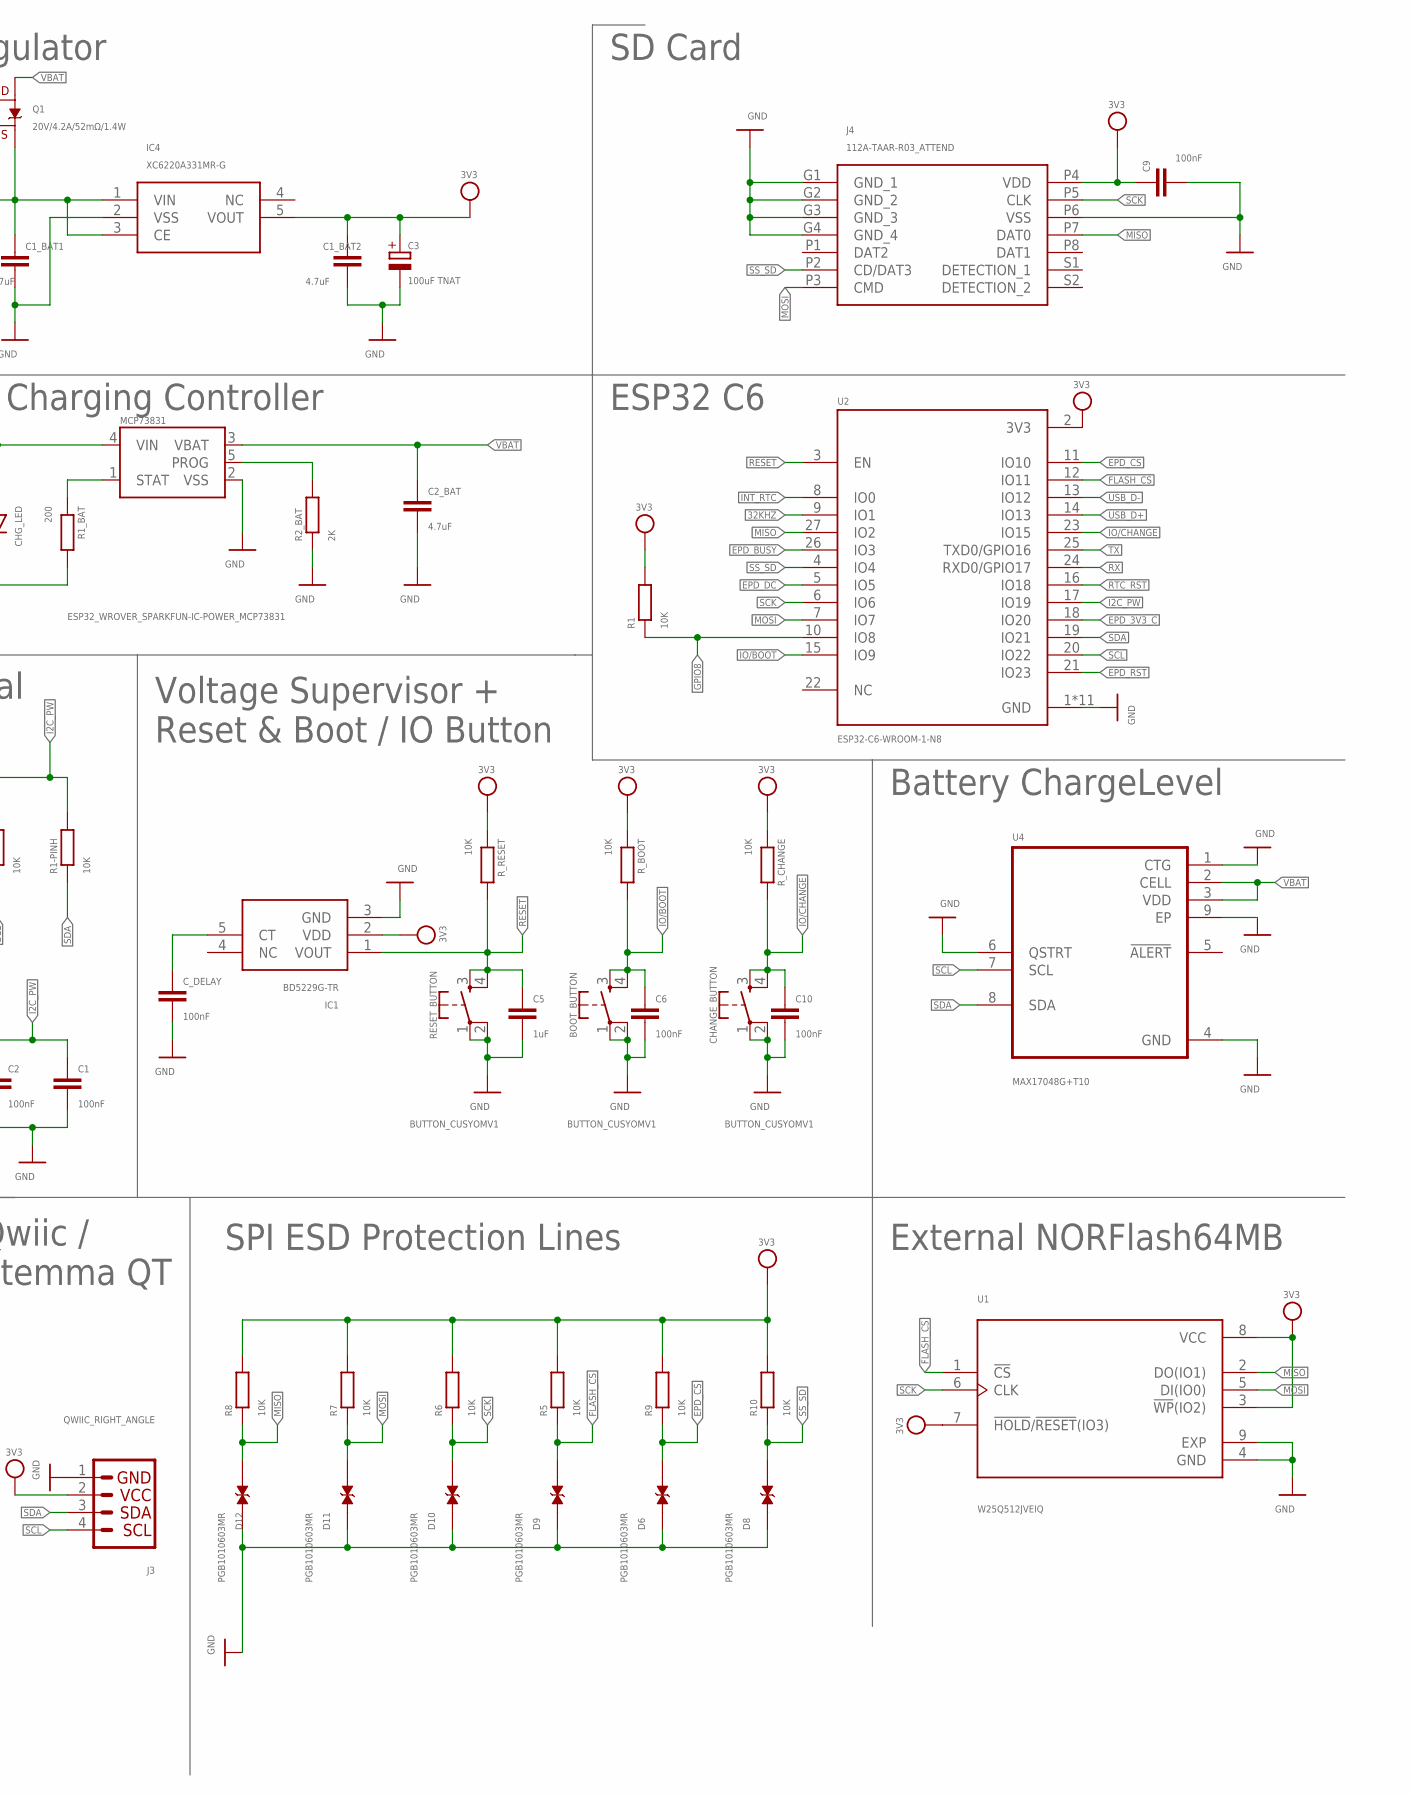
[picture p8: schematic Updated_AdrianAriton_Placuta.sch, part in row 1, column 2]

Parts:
BOOT_BUTTON: BUTTON_CUSYOMV1; MYBUTTON
C1, C2, C6, C8, C9, C10: 100nF; EAGLE-LTSPICE_C0402
C1_BAT, C2_BAT: 4.7uF; EAGLE-LTSPICE_C0402
C1_BAT1, C1_BAT2, C5_USB: 4.7uF; ESP32_WROVER_EAGLE-LTSPICE_C0402
C3: 100uF TNAT; RCL_CT3528
C4: 4.7uF/25V; EAGLE-LTSPICE_C0402
C4_USB: 100nF; ESP32_WROVER_EAGLE-LTSPICE_C0402
C5: 1uF; EAGLE-LTSPICE_C0402
C7: 10uF; EAGLE-LTSPICE_C0402
C10_SUPERCAP: CPH3225A; CAPCP3225X100N
CHANGE_BUTTON: BUTTON_CUSYOMV1; MYBUTTON
CHG_LED: ADAFRUIT_LEDCHIP-LED0603; ADAFRUIT_CHIP-LED0603
C_DELAY: 100nF; EAGLE-LTSPICE_C0402
D1: USBLC6-2SC6Y; SOT95P280X145-6N
D2, D7: ESP32_WROVER_AVX---SD0805S020S1R0_AVX_SD0805S020S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; ESP32_WROVER_AVX---SD0805S020S1R0_AVX_SD0805S020S1R0_0
D3, D4, D5: MBR0530; SOD3716X135N
D6, D8, D9, D10, D11, D12: PGB1010603MR; DIOC1608X36N
EPD_C1, EPD_C2, EPD_C5, EPD_C6, EPD_C7, EPD_C8, EPD_C9, EPD_C10, EPD_C11, EPD_C12: 1uF/50V; EAGLE-LTSPICE_C0402
IC1: BD5229G-TR; SOT95P280X125-5N
IC4: XC6220A331MR-G; SOT95P280X120-5N
J1: FH34SRJ-24S-0.5SH_99_; FH34SRJ24S05SH99
J2: SAMACSYS_PARTS_USB4110-GF-A; SAMACSYS_PARTS_USB4110GFA
J3: QWIIC_RIGHT_ANGLE; JST04_1MM_RA
J4: 112A-TAAR-R03_ATTEND; 112ATAARR03ATTEND
L1: 68uH; IND_4828-WE-TPC_WRE
MCP73831: ESP32_WROVER_SPARKFUN-IC-POWER_MCP73831; SOT95P280X125-5N
PFMF.050.1: ESP32C6_VARISTORCN1812; ESP32C6_VARISTOR_CT/CN1812
Q1, Q2: 20V/4.2A/52mΩ/1.4W; ESP32_WROVER_SPARKFUN-DISCRETESEMI_SOT23-3
Q3: SI1308EDL-T1-GE3; SOT65P210X110-3N
R1, R1-PINH, R1-PINH1, R2-PINH, R2-PINH1, R4, R5, R6, R7, R8, R9, R10: 10K; ESP32_WROVER_EAGLE-LTSPICE_R0402
R1_BAT: 200; ESP32_WROVER_EAGLE-LTSPICE_R0402
R1_PWRUSB: 100K; ESP32_WROVER_EAGLE-LTSPICE_R0402
R2: 2.2; ESP32_WROVER_EAGLE-LTSPICE_R0402
R2-USB, R2-USB1: 5k1; ESP32_WROVER_EAGLE-LTSPICE_R0402
R2_BAT: 2K; ESP32_WROVER_EAGLE-LTSPICE_R0402
R3: 0.47; ESP32_WROVER_EAGLE-LTSPICE_R0402
RESET_BUTTON: BUTTON_CUSYOMV1; MYBUTTON
R_BOOT: 10K; ESP32_WROVER_EAGLE-LTSPICE_R0402
R_CAPACITOR: 15; ESP32_WROVER_EAGLE-LTSPICE_R0402
R_CHANGE: 10K; ESP32_WROVER_EAGLE-LTSPICE_R0402
R_CL1: 10K; ESP32_WROVER_EAGLE-LTSPICE_R0402
R_RESET: 10K; ESP32_WROVER_EAGLE-LTSPICE_R0402
SENSOR2: ESP32_WROVER_BME680_BME680; ESP32_WROVER_BME680_PSON80P300X300X100-8N
SJ1: SJ
TP1, TP2, TP3, TP4, TP5, TP6, TP7, TP8, TP9, TP10, TP11, TP12, TP13, TP14, TP15, TP16, TP17: TPTP20R; TP20R
U1: W25Q512JVEIQ; SON127P600X800X80-9N
U2: ESP32-C6-WROOM-1-N8; XCVR_ESP32-C6-WROOM-1-N8
U3: DS3231SN#; SOIC127P1032X265-16N
U4: MAX17048G+T10; SON50P200X200X80-9N

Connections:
3V3: C1_BAT2.1, C3.+, C9.1, D7.2 (ANODE), IC1.2 (VDD), IC4.5 (VOUT), J3.2, J4.P4 (VDD), Q2.3 (D), R1.2, R1-PINH1.2, R2-PINH1.2, R5.2, R6.2, R7.2, R8.2, R9.2, R10.2, R_BOOT.1, R_CHANGE.1, R_CL1.1, R_RESET.2, TP16.TP, U1.3 (!WP!(IO2)), U1.7 (!HOLD!/!RESET!(IO3)), U1.8 (VCC), U2.2 (3V3), U3.2 (VCC)
32KHZ: R2-PINH1.1, U2.9 (IO1), U3.1 (32KHZ)
DN: D1.1 (I/O1_1), J2.A7, J2.B7
DP: D1.3 (I/O2_1), J2.A6, J2.B6
EPD_3V3: C7.1, EPD_C5.1, J1.15, J1.16, L1.2, Q2.2 (S), TP17.TP
EPD_3V3_C: Q2.1 (G), R_CL1.2, TP13.TP, U2.18 (IO20)
EPD_BUSY: J1.9, TP9.TP, U2.26 (IO3)
EPD_CS: D6.2, J1.12, R9.1, TP10.TP, U2.11 (IO10)
EPD_DC: J1.11, TP11.TP, U2.5 (IO5)
EPD_RST: J1.10, TP12.TP, U2.21 (IO23)
FLASH_CS: D9.2, R5.1, U1.1 (!CS), U2.12 (IO11)
GDR: J1.2, Q3.1 (G), R4.1
GND: BOOT_BUTTON.1, BOOT_BUTTON.2, C1.2, C1_BAT.2, C1_BAT1.2, C1_BAT2.2, C2.2, C2_BAT.2, C3.-, C4_USB.2, C5.2, C5_USB.2, C6.2, C7.2, C8.2, C9.2, C10.2, C10_SUPERCAP.1, CHANGE_BUTTON.1, CHANGE_BUTTON.2, C_DELAY.2, D1.5 (VBUS), D3.1 (K), D6.1, D8.1, D9.1, D10.1, D11.1, D12.1, EPD_C1.2, EPD_C2.2, EPD_C5.2, EPD_C6.2, EPD_C7.2, EPD_C8.2, EPD_C9.2, EPD_C10.2, EPD_C11.2, EPD_C12.2, IC1.3 (GND), IC4.2 (VSS), J1.8, J1.17, J1.MP1, J1.MP2, J2.A1, J2.A12, J2.B1, J2.B12, J2.MP1, J2.MP2, J2.MP3, J2.MP4, J3.1, J4.G1 (GND_1), J4.G2 (GND_2), J4.G3 (GND_3), J4.G4 (GND_4), J4.P6 (VSS), MCP73831.2 (VSS), R1_PWRUSB.1, R2.1, R2-USB.2, R2-USB1.1, R2_BAT.1, R4.2, RESET_BUTTON.1, RESET_BUTTON.2, SENSOR2.1 (GND), SENSOR2.5 (SDO), SENSOR2.7 (GND), SJ1.1, TP4.TP, TP5.TP, U1.4 (GND), U1.9 (EXP), U2.1 (GND), U2.28 (GND), U2.29_1 (GND), U2.29_2 (GND), U2.29_3 (GND), U2.29_4 (GND), U2.29_5 (GND), U2.29_6 (GND), U2.29_7 (GND), U2.29_8 (GND), U2.29_9 (GND), U3.13 (GND), U4.1 (CTG), U4.4 (GND), U4.6 (QSTRT), U4.9 (EP)
GPIO8: R1.1, U2.10 (IO8)
I2C_PW: C1.1, C2.1, R1-PINH.2, R2-PINH.2, SENSOR2.2 (CSB), SENSOR2.6 (VDDIO), SENSOR2.8 (VDD), U2.17 (IO19)
INT_RTC: R1-PINH1.1, TP15.TP, U2.8 (IO0), U3.3 (SQW/!INT)
IO/BOOT: BOOT_BUTTON.3, BOOT_BUTTON.4, C6.1, R_BOOT.2, U2.15 (IO9)
IO/CHANGE: C10.1, CHANGE_BUTTON.3, CHANGE_BUTTON.4, R_CHANGE.2, U2.23 (IO15)
MISO: D12.2, J4.P7 (DAT0), R8.1, TP6.TP, U1.2 (DO(IO1)), U2.27 (IO2)
MOSI: D11.2, J1.14, J4.P3 (CMD), R7.1, TP7.TP, U1.5 (DI(IO0)), U2.7 (IO7)
unnamed: J2.B5, R2-USB.1
unnamed: C1_BAT1.1, D2.1 (CATHODE), IC4.1 (VIN), IC4.3 (CE), Q1.2 (S)
unnamed: MCP73831.1 (STAT), R1_BAT.1
unnamed: J2.A5, R2-USB1.2
unnamed: CHG_LED.C, R1_BAT.2
unnamed: C4.1, D3.2 (A), D4.1 (K)
unnamed: EPD_C12.1, J1.24
unnamed: MCP73831.5 (PROG), R2_BAT.2
unnamed: C_DELAY.1, IC1.5 (CT)
unnamed: EPD_C10.1, J1.22
unnamed: EPD_C8.1, J1.20
unnamed: EPD_C7.1, J1.19
unnamed: EPD_C6.1, J1.18
unnamed: D7.1 (CATHODE), R_CAPACITOR.2
unnamed: EPD_C1.1, J1.4
unnamed: EPD_C2.1, J1.5
PREVGH: D5.1 (K), EPD_C9.1, J1.21
PREVGL: D4.2 (A), EPD_C11.1, J1.23
RESE: J1.3, Q3.2 (S), R3.1
RESE': R2.2, R3.2, SJ1.2
RESET: C5.1, IC1.1 (VOUT), RESET_BUTTON.3, RESET_BUTTON.4, R_RESET.1, U2.3 (EN)
RTC_RST: U2.16 (IO18), U3.4 (!RST)
RX: TP2.TP, U2.24 (RXD0/GPIO17)
SCK: D10.2, J1.13, J4.P5 (CLK), R6.1, TP8.TP, U1.6 (CLK), U2.6 (IO6)
SCL: J3.4, R2-PINH.1, SENSOR2.4 (SCK), U2.20 (IO22), U3.16 (SCL), U4.7 (SCL)
SDA: J3.3, R1-PINH.1, SENSOR2.3 (SDI), U2.19 (IO21), U3.15 (SDA), U4.8 (SDA)
SRC: C4.2, D5.2 (A), L1.1, Q3.3 (D)
SS_SD: D8.2, J4.P2 (CD/DAT3), R10.1, U2.4 (IO4)
TX: TP1.TP, U2.25 (TXD0/GPIO16)
USB_D+: D1.4 (I/O2_2), U2.14 (IO13)
USB_D-: D1.6 (I/O1_2), U2.13 (IO12)
VBAT: C2_BAT.1, MCP73831.3 (VBAT), Q1.3 (D), TP3.TP, U4.2 (CELL), U4.3 (VDD)
VBUS: C1_BAT.1, C4_USB.1, C5_USB.1, CHG_LED.A, D1.2 (GND), D2.2 (ANODE), MCP73831.4 (VIN), PFMF.050.1.2, Q1.1 (G), R1_PWRUSB.2, TP14.TP
VRTC: C8.1, C10_SUPERCAP.2, R_CAPACITOR.1, U3.14 (VBAT)
VUSB: J2.A4, J2.A9, J2.B4, J2.B9, PFMF.050.1.1

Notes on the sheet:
USB C connector & ESD protection
LDO Voltage Regulator
SD Card
Display Type Selector
E-Paper Drive Circuit
Li-Po Battery Charging Controller
ESP32 C6
E-Paper Display Header
EPD Power
Environmental Sensor BME688
Voltage Supervisor + Reset & Boot / IO Button
Battery ChargeLevel
RTC Module DS3231SN
Test Pads
Qwiic / Stemma QT
SPI ESD Protection Lines
External NORFlash64MB

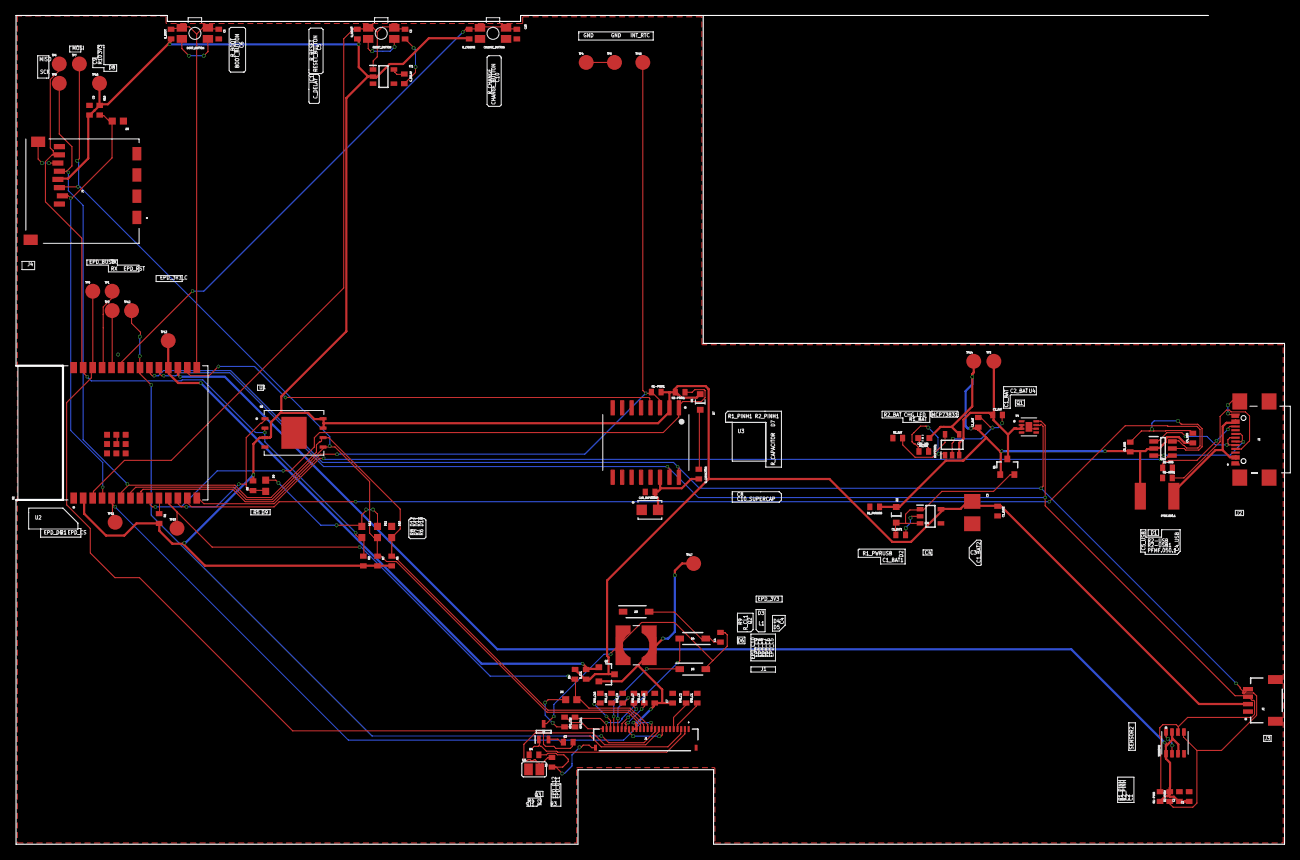
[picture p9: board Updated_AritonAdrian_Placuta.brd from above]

Board: 2 copper layers, 170.2 x 111.2 mm, 103 parts (0 on the bottom side), 55 nets.

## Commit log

2025-04-05 added link file
    [links_and_models.xlsx]
2025-04-14 fixed issues
    [F3Z OpenBook Enclosure 2 v13.f3z, PickAndPlace.csv, Tema1TSC v59.brd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]

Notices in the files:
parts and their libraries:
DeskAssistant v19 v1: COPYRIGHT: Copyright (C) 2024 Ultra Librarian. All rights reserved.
